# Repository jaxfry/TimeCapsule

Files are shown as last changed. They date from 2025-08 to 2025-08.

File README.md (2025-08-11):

# Time Capsule USB

## Description

**What is Time Capsule USB?**

Time Capsule USB is a custom PCB using the RP2040 microcontroller that functions as a sort of time capsule. It alows you upload files to it, which can only be accessed after a certain date that you set. Due to the limits of battery life, it's not meant to be used for long-term storage, but it should last about 7 years and then about 1 year of the LED blinking to indicate that the time has come to access the files. The main limit is that CR2032 batteries only last about 10 years and naturally discharge over time.

---

## Why I Made This

I wanted to create a simple yet fun project that would allow me to learn about PCB design and microcontrollers, using RTC and other components, I felt like I learned a lot!

---

## Features
- **RP2040 Microcontroller**: Wow! It's micro, and it controls things!
- **Storage**: A whopping 16MB of flash storage for the code and files you want to store!
- **Time Lock**: Just name the file the date you want to unlock it.
- **Battery Life**: Powered by a CR2032 battery, it can last up to 7 years. Meaning, don't go past that date, or you will lose the files!
- **RTC**: Super duper efficient clock that runs on battery for years.
- **LED indicator**: Thats right, IT EVEN HAS AN LED! Once a file is ready to be accessed, the LED will blink to indicate that the time has come. it can do this for about a year before the battery dies.

---

## How to Use
1. **Upload Files**: Connect the Time Capsule USB to your computer and upload files to it. (will appear as a USB drive)
2. **Set Unlock Date**: Name the file with the date you want to unlock it (e.g., `2025-12-31.txt`).
3. **Disconnect**: Your files will no longer appear until the date!

---

## Project Pictures
Time Capsule USB PCB

### Bill of Materials (BOM)
|Reference |Qty |Value |DNP|Exclude from BOM|Exclude from Board|Footprint |Datasheet |MANUFACTURER |MPN |DIGIKEY # |Price |Link |
|---|---|---|---|---|---|---|---|---|---|---|---|---|
|BT1 |1 |Battery_Cell | | | |Battery:BatteryHolder_Keystone_106_1x20mm |~ |Keystone Electronics |106 |36-106-ND |1.38000 |https://www.digikey.ca/en/products/detail/keystone-electronics/106/27386 |
|C1,C9,C13 |3 |1u | | | |Capacitor_SMD:C_0402_1005Metric_Pad0.74x0.62mm_HandSolder |~ |TDK Corporation |C1005X5R1E105K050EC |445-C1005X5R1E105K050ECCT-ND |0.16000 |https://www.digikey.ca/en/products/detail/tdk-corporation/C1005X5R1E105K050EC/22106056 |
|C2,C3,C4,C5,C6,C7,C8,C10,C11,C14|10 |100n | | | |Capacitor_SMD:C_0402_1005Metric_Pad0.74x0.62mm_HandSolder |~ |Samsung Electro-Mechanics |CL05B104KP5VPNC |1276-CL05B104KP5VPNCCT-ND |0.05300 |https://www.digikey.ca/en/products/detail/samsung-electro-mechanics/CL05B104KP5VPNC/20498482 |
|C12,C18 |2 |4.7uF | | | |Capacitor_SMD:C_0402_1005Metric_Pad0.74x0.62mm_HandSolder |~ |Samsung Electro-Mechanics |CL05A475MP5NRNC |1276-1482-1-ND |0.12000 |https://www.digikey.ca/en/products/detail/samsung-electro-mechanics/CL05A475MP5NRNC/3887140 |
|C15,C16 |2 |15p | | | |Capacitor_SMD:C_0402_1005Metric_Pad0.74x0.62mm_HandSolder |~ |Murata Electronics |GJM1555C1H150GB01D |490-8080-1-ND |0.17000 |https://www.digikey.ca/en/products/detail/murata-electronics/GJM1555C1H150GB01D/2592856 |
|C17 |1 |0.1u | | | |Capacitor_SMD:C_0402_1005Metric_Pad0.74x0.62mm_HandSolder |~ |Samsung Electro-Mechanics |CL05B104KP5NNNC |1276-1002-1-ND |0.12000 |https://www.digikey.ca/en/products/detail/samsung-electro-mechanics/CL05B104KP5NNNC/3886660 |
|D1 |1 |LED | | | |LED_SMD:LED_0805_2012Metric |~ |ams-OSRAM USA INC. |LS R976-NR-1-0-20-R18 |475-LSR976-NR-1CT-ND |0.23000 |https://www.digikey.ca/en/products/detail/ams-osram-usa-inc/LS-R976-NR-1-0-20-R18/1227987 |
|D2 |1 |1N4148 | | | |Diode_THT:D_DO-35_SOD27_P7.62mm_Horizontal |https://assets.nexperia.com/documents/data-sheet/1N4148_1N4448.pdf |MCC (Micro Commercial Components)|1N4148WL2-TP |1N4148WL2-TPMSCT-ND |0.19000 |https://www.digikey.ca/en/products/detail/mcc-micro-commercial-components/1N4148WL2-TP/6193188 |
|J1 |1 |USB_C_Receptacle_USB2.0_14P| | | |Connector_USB:USB_C_Receptacle_GCT_USB4105-xx-A_16P_TopMnt_Horizontal|https://www.usb.org/sites/default/files/documents/usb_type-c.zip |GCT |USB4105-GF-A |USB4105-GF-A |1.12000 |https://www.digikey.ca/en/products/detail/gct/USB4105-GF-A/11198441 |
|Q1 |1 |Q_PMOS_GSD | | | |Package_TO_SOT_SMD:SOT-23 |~ |Diodes Incorporated |DMP2305U-7 |DMP2305UDICT-ND |0.40000 |https://www.digikey.ca/en/products/detail/diodes-incorporated/DMP2305U-7/2052779 |
|Q2,Q3,Q4 |3 |Q_NMOS_GSD | | | |Package_TO_SOT_SMD:SOT-23 |~ |Diotec Semiconductor |2N7002 |4878-2N7002CT-ND |0.19000 |https://www.digikey.ca/en/products/detail/diotec-semiconductor/2N7002/13163336 |
|R1,R2 |2 |5.1k | | | |Resistor_SMD:R_0402_1005Metric_Pad0.72x0.64mm_HandSolder |~ |YAGEO |RC0402FR-075K1L |311-5.10KLRCT-ND |0.15000 |https://www.digikey.ca/en/products/detail/yageo/RC0402FR-075K1L/726624 |
|R3,R4 |2 |27.4 | | | |Resistor_SMD:R_0402_1005Metric_Pad0.72x0.64mm_HandSolder |~ |Stackpole Electronics Inc |RMCF0402FT27R4 |738-RMCF0402FT27R4CT-ND |0.15000 |https://www.digikey.ca/en/products/detail/stackpole-electronics-inc/RMCF0402FT27R4/1761590 |
|R6,R7 |2 |1k | | | |Resistor_SMD:R_0402_1005Metric_Pad0.72x0.64mm_HandSolder |~ |Stackpole Electronics Inc |RMCF0402FT1K00 |RMCF0402FT1K00CT-ND |0.15000 |https://www.digikey.ca/en/products/detail/stackpole-electronics-inc/RMCF0402FT1K00/1761754 |
|R8,R9 |2 |4.7k | | | |Resistor_SMD:R_0402_1005Metric_Pad0.72x0.64mm_HandSolder |~ |YAGEO |RC0402FR-074K7L |311-4.7KLRCT-ND |0.15000 |https://www.digikey.ca/en/products/detail/yageo/RC0402FR-074K7L/2827563 |
|R10 |1 |1M | | | |Resistor_SMD:R_0402_1005Metric_Pad0.72x0.64mm_HandSolder |~ |TE Connectivity Passive Product  |CRGCQ0402F1M0 |A129663CT-ND |0.15000 |https://www.digikey.ca/en/products/detail/te-connectivity-passive-product/CRGCQ0402F1M0/8576265 |
|R11 |1 |16.9k | | | |Resistor_SMD:R_0402_1005Metric_Pad0.72x0.64mm_HandSolder |~ |Panasonic Electronic Components  |ERJ-2RKF1692X |P16.9KLCT-ND |0.15000 |https://www.digikey.ca/en/products/detail/panasonic-electronic-components/ERJ-2RKF1692X/192161 |
|R12,R14,R16 |3 |10k | | | |Resistor_SMD:R_0402_1005Metric_Pad0.72x0.64mm_HandSolder |~ |Samsung Electro-Mechanics |RC1005F103CS |1276-3431-1-ND |0.15000 |https://www.digikey.ca/en/products/detail/samsung-electro-mechanics/RC1005F103CS/3903439 |
|R13 |1 |150 |DNP| | |Resistor_SMD:R_0402_1005Metric_Pad0.72x0.64mm_HandSolder |~ |Stackpole Electronics Inc |RMCF0402FT150R |RMCF0402FT150RCT-ND |0.15000 |https://www.digikey.ca/en/products/detail/stackpole-electronics-inc/RMCF0402FT150R/1761826 |
|R15 |1 |100k | | | |Resistor_SMD:R_0402_1005Metric_Pad0.72x0.64mm_HandSolder |~ |Vishay Dale |CRCW0402100KFKED |541-100KLCT-ND |0.15000 |https://www.digikey.ca/en/products/detail/vishay-dale/CRCW0402100KFKED/1178235 |
|SW1,SW2 |2 |SW_Push | | | |Button_Switch_THT:SW_PUSH_6mm |~ |Omron Electronics Inc-EMC Div |B3F-1020 |SW402-ND |0.43000 |https://www.digikey.ca/en/products/detail/omron-electronics-inc-emc-div/B3F-1020/44059 |
|U1 |1 |RP2040 | | | |Package_DFN_QFN:QFN-56-1EP_7x7mm_P0.4mm_EP3.2x3.2mm |https://datasheets.raspberrypi.com/rp2040/rp2040-datasheet.pdf |Raspberry Pi |SC0914(13) |2648-SC0914(13)CT-ND |1.07000 |https://www.digikey.ca/en/products/detail/raspberry-pi/SC0914-13/14306010 |
|U2 |1 |TPL5110 | | | |Package_TO_SOT_SMD:SOT-23-6 |http://www.ti.com/lit/ds/symlink/tpl5110.pdf |Texas Instruments |TPL5110QDDCRQ1 |296-47866-1-ND |1.24000 |https://www.digikey.ca/en/products/detail/texas-instruments/TPL5110QDDCRQ1/6816812 |
|U3 |1 |AP2112K-3.3 | | | |Package_TO_SOT_SMD:SOT-23-5 |https://www.diodes.com/assets/Datasheets/AP2112.pdf |Diodes Incorporated |AP2112K-3.3TRG1 |AP2112K-3.3TRG1DICT-ND |0.34000 |https://www.digikey.ca/en/products/detail/diodes-incorporated/AP2112K-3-3TRG1/4470746 |
|U4 |1 |RV-3028-C7 | | | |Package_SON:MicroCrystal_C7_SON-8_1.5x3.2mm_P0.9mm |https://www.microcrystal.com/fileadmin/Media/Products/RTC/Datasheet/RV-3028-C7.pdf|Micro Crystal AG |RV-3028-C7 32.768KHZ 1PPM-TA-QC|2195-RV-3028-C732.768KHZ1PPM-TA-QCCT-ND|3.91000 |https://www.digikey.ca/en/products/detail/micro-crystal-ag/RV-3028-C7-32-768KHZ-1PPM-TA-QC/10431070|
|U5 |1 |W25Q128JVS | | | |Package_SO:SOIC-8_5.3x5.3mm_P1.27mm |https://www.winbond.com/resource-files/w25q128jv_dtr%20revc%2003272018%20plus.pdf |Winbond Electronics |W25Q128JVSIQ TR |256-W25Q128JVSIQTRCT-ND |2.35000 |https://www.digikey.ca/en/products/detail/winbond-electronics/W25Q128JVSIQ-TR/5803944 |
|U6 |1 |74LVC1G32 | | | |Package_TO_SOT_SMD:SOT-23-5 |http://www.ti.com/lit/sg/scyt129e/scyt129e.pdf |Texas Instruments |SN74LVC1G32DBVR |296-9847-1-ND |0.17000 |https://www.digikey.ca/en/products/detail/texas-instruments/SN74LVC1G32DBVR/381323 |
|Y1 |1 |ABM8-272-T3 | | | |Crystal:Crystal_SMD_3225-4Pin_3.2x2.5mm | |ABRACON |ABM8-272-T3 |535-ABM8-272-T3CT-ND |0.83000 |https://www.digikey.ca/en/products/detail/abracon-llc/ABM8-272-T3/22472366 |
|PCB |5 (minimum)| | | | | | | | |PCB |$2.76 (exc. shipping), $35.01 (CAD) (including shipping)|JLCPCB |
| | | | | | | | | | |Total | |$21.38 (CAD) (excluding shipping, taxes) |

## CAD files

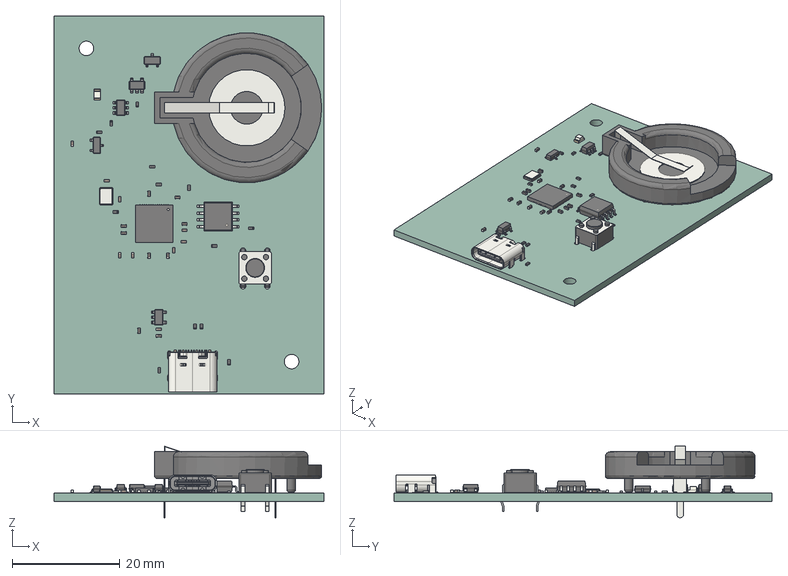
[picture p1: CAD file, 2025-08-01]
TimeCapsulePCB/TimeCapsule.step
50.0 x 70.0 x 13.2 mm
R_0402_1005Metric x 13
C_0402_1005Metric x 18
SOT-23-6
QFN-56-1EP_7x7mm_P0.4mm_EP3.2x3.2mm
SW_PUSH_6mm
SOIC-8_5.3x5.3mm_P1.27mm
SOT-23-5 x 2
SOT-23 x 2
BatteryHolder_Keystone_106_1x20mm
LED_0805_2012Metric
Crystal_SMD_3225-4Pin_3.2x2.5mm
USB_C_Receptacle_GCT_USB4105-xx-A_16P_TopMnt_Horizontal
TimeCapsule_PCB

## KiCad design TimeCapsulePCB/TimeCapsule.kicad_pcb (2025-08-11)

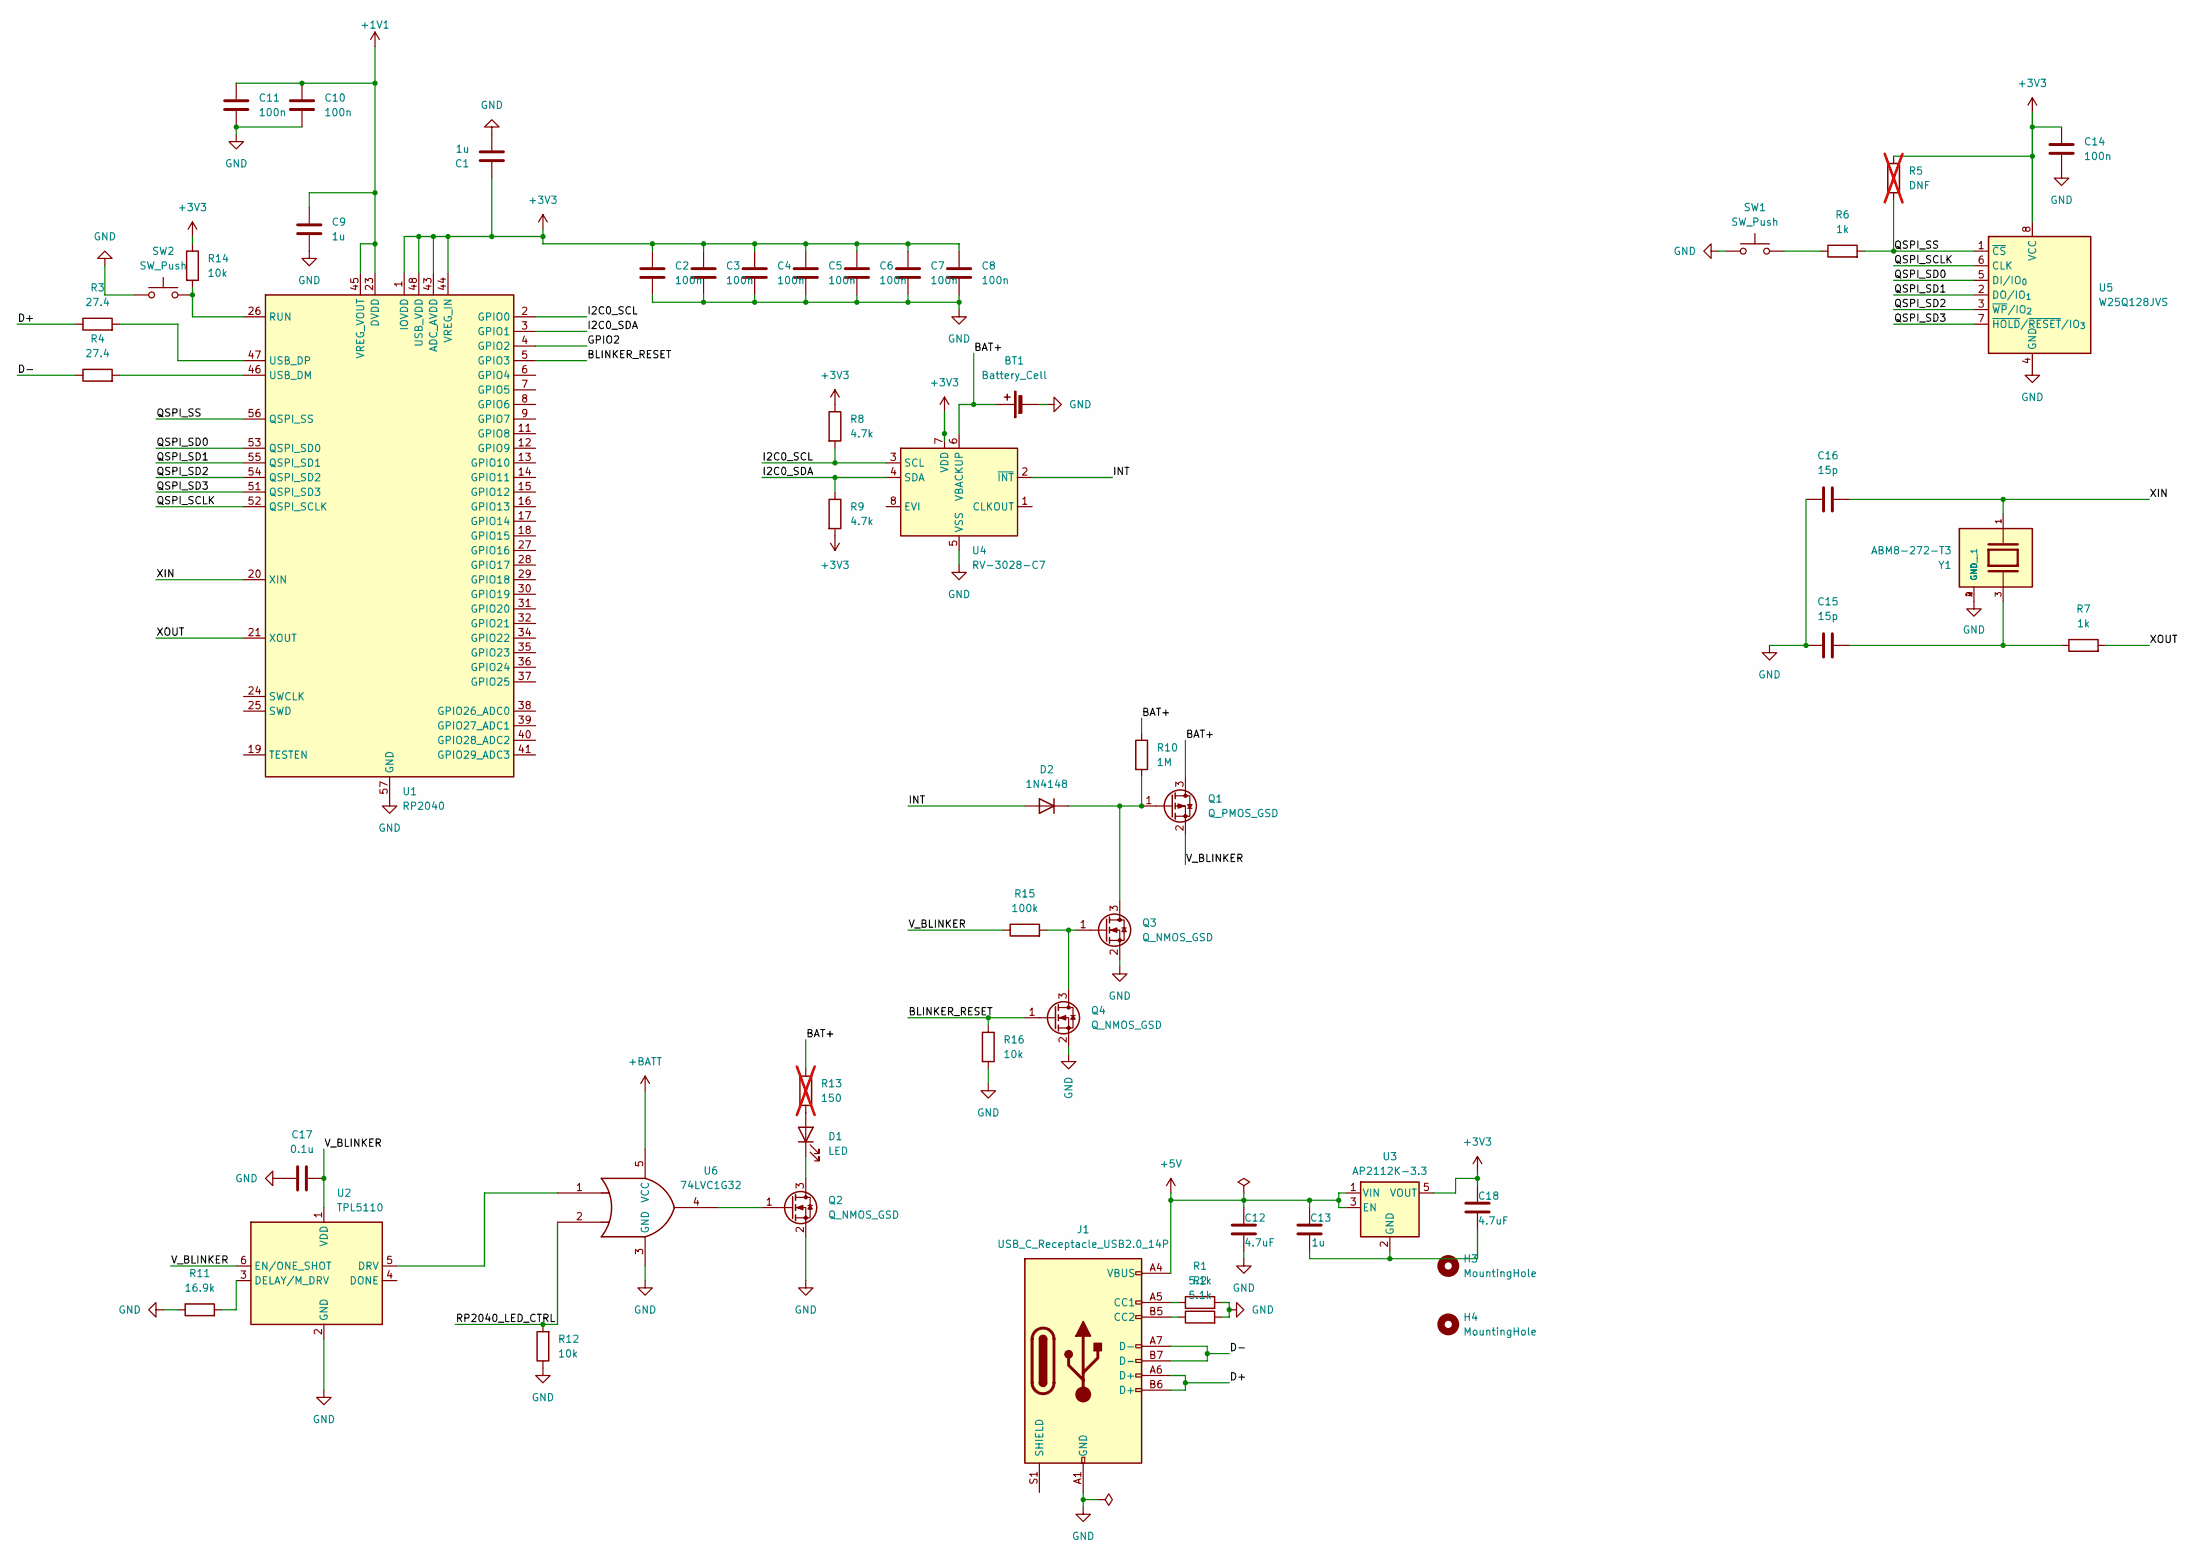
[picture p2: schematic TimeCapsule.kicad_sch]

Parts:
BT1: Battery_Cell; BatteryHolder_Keystone_106_1x20mm; MPN 106; DIGIKEY # 36-106-ND
C1, C9, C13: 1u; C_0402_1005Metric_Pad0.74x0.62mm_HandSolder; MPN C1005X5R1E105K050EC; DIGIKEY # 445-C1005X5R1E105K050ECCT-ND
C2, C3, C4, C5, C6, C7, C8, C10, C11, C14: 100n; C_0402_1005Metric_Pad0.74x0.62mm_HandSolder; MPN CL05B104KP5VPNC; DIGIKEY # 1276-CL05B104KP5VPNCCT-ND
C12, C18: 4.7uF; C_0402_1005Metric_Pad0.74x0.62mm_HandSolder; MPN CL05A475MP5NRNC; DIGIKEY # 1276-1482-1-ND
C15, C16: 15p; C_0402_1005Metric_Pad0.74x0.62mm_HandSolder; MPN GJM1555C1H150GB01D; DIGIKEY # 490-8080-1-ND
C17: 0.1u; C_0402_1005Metric_Pad0.74x0.62mm_HandSolder; MPN CL05B104KP5NNNC; DIGIKEY # 1276-1002-1-ND
D1: LED; LED_0805_2012Metric; MPN LS R976-NR-1-0-20-R18; DIGIKEY # 475-LSR976-NR-1CT-ND
D2: 1N4148; D_DO-35_SOD27_P7.62mm_Horizontal; MPN 1N4148WL2-TP; DIGIKEY # 1N4148WL2-TPMSCT-ND
H3, H4: MountingHole; MountingHole_2.7mm_M2.5
J1: USB_C_Receptacle_USB2.0_14P; USB_C_Receptacle_GCT_USB4105-xx-A_16P_TopMnt_Horizontal; MPN USB4105-GF-A; DIGIKEY # USB4105-GF-A
Q1: Q_PMOS_GSD; SOT-23; MPN DMP2305U-7; DIGIKEY # DMP2305UDICT-ND
Q2, Q3, Q4: Q_NMOS_GSD; SOT-23; MPN 2N7002; DIGIKEY # 4878-2N7002CT-ND
R1, R2: 5.1k; R_0402_1005Metric_Pad0.72x0.64mm_HandSolder; MPN RC0402FR-075K1L; DIGIKEY # 311-5.10KLRCT-ND
R3, R4: 27.4; R_0402_1005Metric_Pad0.72x0.64mm_HandSolder; MPN RMCF0402FT27R4; DIGIKEY # 738-RMCF0402FT27R4CT-ND
R5: DNF; R_0402_1005Metric_Pad0.72x0.64mm_HandSolder; not fitted
R6, R7: 1k; R_0402_1005Metric_Pad0.72x0.64mm_HandSolder; MPN RMCF0402FT1K00; DIGIKEY # RMCF0402FT1K00CT-ND
R8, R9: 4.7k; R_0402_1005Metric_Pad0.72x0.64mm_HandSolder; MPN RC0402FR-074K7L; DIGIKEY # 311-4.7KLRCT-ND
R10: 1M; R_0402_1005Metric_Pad0.72x0.64mm_HandSolder; MPN CRGCQ0402F1M0; DIGIKEY # A129663CT-ND
R11: 16.9k; R_0402_1005Metric_Pad0.72x0.64mm_HandSolder; MPN ERJ-2RKF1692X; DIGIKEY # P16.9KLCT-ND
R12, R14, R16: 10k; R_0402_1005Metric_Pad0.72x0.64mm_HandSolder; MPN RC1005F103CS; DIGIKEY # 1276-3431-1-ND
R13: 150; R_0402_1005Metric_Pad0.72x0.64mm_HandSolder; MPN RMCF0402FT150R; DIGIKEY # RMCF0402FT150RCT-ND; not fitted
R15: 100k; R_0402_1005Metric_Pad0.72x0.64mm_HandSolder; MPN CRCW0402100KFKED; DIGIKEY # 541-100KLCT-ND
SW1, SW2: SW_Push; SW_PUSH_6mm; MPN B3F-1020; DIGIKEY # SW402-ND
U1: RP2040; QFN-56-1EP_7x7mm_P0.4mm_EP3.2x3.2mm; MPN SC0914(13); DIGIKEY # 2648-SC0914(13)CT-ND
U2: TPL5110; SOT-23-6; MPN TPL5110QDDCRQ1; DIGIKEY # 296-47866-1-ND
U3: AP2112K-3.3; SOT-23-5; MPN AP2112K-3.3TRG1; DIGIKEY # AP2112K-3.3TRG1DICT-ND
U4: RV-3028-C7; MicroCrystal_C7_SON-8_1.5x3.2mm_P0.9mm; MPN RV-3028-C7 32.768KHZ 1PPM-TA-QC; DIGIKEY # 2195-RV-3028-C732.768KHZ1PPM-TA-QCCT-ND
U5: W25Q128JVS; SOIC-8_5.3x5.3mm_P1.27mm; MPN W25Q128JVSIQ TR; DIGIKEY # 256-W25Q128JVSIQTRCT-ND
U6: 74LVC1G32; SOT-23-5; MPN SN74LVC1G32DBVR; DIGIKEY # 296-9847-1-ND
Y1: ABM8-272-T3; Crystal_SMD_3225-4Pin_3.2x2.5mm; PARTREV 07-29-20; DIGIKEY # 535-ABM8-272-T3CT-ND

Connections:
+1V1: C9.1, C10.1, C11.1, U1.23 (DVDD), U1.45 (VREG_VOUT), U1.50 (DVDD)
+3V3: C1.1, C2.1, C3.1, C4.1, C5.1, C6.1, C7.1, C8.1, C14.1, C18.1, R5.1, R8.1, R9.2, R14.1, U1.1 (IOVDD), U1.10 (IOVDD), U1.22 (IOVDD), U1.33 (IOVDD), U1.42 (IOVDD), U1.43 (ADC_AVDD), U1.44 (VREG_IN), U1.48 (USB_VDD), U1.49 (IOVDD), U3.5 (VOUT), U4.7 (VDD), U5.8 (VCC)
+5V: C12.1, C13.1, J1.A4 (VBUS), J1.A9 (VBUS), J1.B4 (VBUS), J1.B9 (VBUS), U3.1 (VIN), U3.3 (EN)
+BATT: U6.5 (VCC)
/BAT+: BT1.1 (+), Q1.3 (D), R10.1, R13.1, U4.6 (VBACKUP)
/BLINKER_RESET: Q4.1 (G), R16.1, U1.5 (GPIO3)
/D+: J1.A6 (D+), J1.B6 (D+), R3.1
/D-: J1.A7 (D-), J1.B7 (D-), R4.1
/GPIO2: U1.4 (GPIO2)
/I2C0_SCL: R8.2, U1.2 (GPIO0), U4.3 (SCL)
/I2C0_SDA: R9.1, U1.3 (GPIO1), U4.4 (SDA)
/INT: D2.2 (A), U4.2 (~INT)
/QSPI_SCLK: U1.52 (QSPI_SCLK), U5.6 (CLK)
/QSPI_SD0: U1.53 (QSPI_SD0), U5.5 (DI/IO_{0})
/QSPI_SD1: U1.55 (QSPI_SD1), U5.2 (DO/IO_{1})
/QSPI_SD2: U1.54 (QSPI_SD2), U5.3 (~WP/IO_{2})
/QSPI_SD3: U1.51 (QSPI_SD3), U5.7 (~HOLD/~RESET/IO_{3})
/QSPI_SS: R5.2, R6.2, U1.56 (QSPI_SS), U5.1 (~CS)
/RP2040_LED_CTRL: R12.2, U6.2
/V_BLINKER: C17.2, Q1.2 (S), R15.1, U2.1 (VDD), U2.6 (EN/ONE_SHOT)
/XIN: C16.2, U1.20 (XIN), Y1.1
/XOUT: R7.2, U1.21 (XOUT)
GND: BT1.2 (-), C1.2, C2.2, C3.2, C4.2, C5.2, C6.2, C7.2, C8.2, C9.2, C10.2, C11.2, C12.2, C14.2, C15.1, C16.1, C17.1, J1.A1 (GND), J1.A12 (GND), J1.B1 (GND), J1.B12 (GND), Q2.2 (S), Q3.2 (S), Q4.2 (S), R1.2, R2.2, R11.1, R12.1, R16.2, SW1.1, SW2.1, U1.57 (GND), U2.2 (GND), U4.5 (VSS), U5.4 (GND), U6.3 (GND), Y1.2 (GND), Y1.4 (GND__1)
unnamed: C15.2, R7.1, Y1.3
unnamed: D1.2 (A), R13.2
unnamed: D1.1 (K), Q2.3 (D)
unnamed: D2.1 (K), Q1.1 (G), Q3.3 (D), R10.2
unnamed: J1.A5 (CC1), R1.1
unnamed: J1.B5 (CC2), R2.1
unnamed: Q2.1 (G), U6.4
unnamed: Q3.1 (G), Q4.3 (D), R15.2
unnamed: R6.1, SW1.2
unnamed: R14.2, SW2.2, U1.26 (RUN)
unnamed: R4.2, U1.46 (USB_DM)
unnamed: R3.2, U1.47 (USB_DP)
unnamed: R11.2, U2.3 (DELAY/M_DRV)
unnamed: U2.5 (DRV), U6.1
unnamed: C13.2, C18.2, U3.2 (GND)

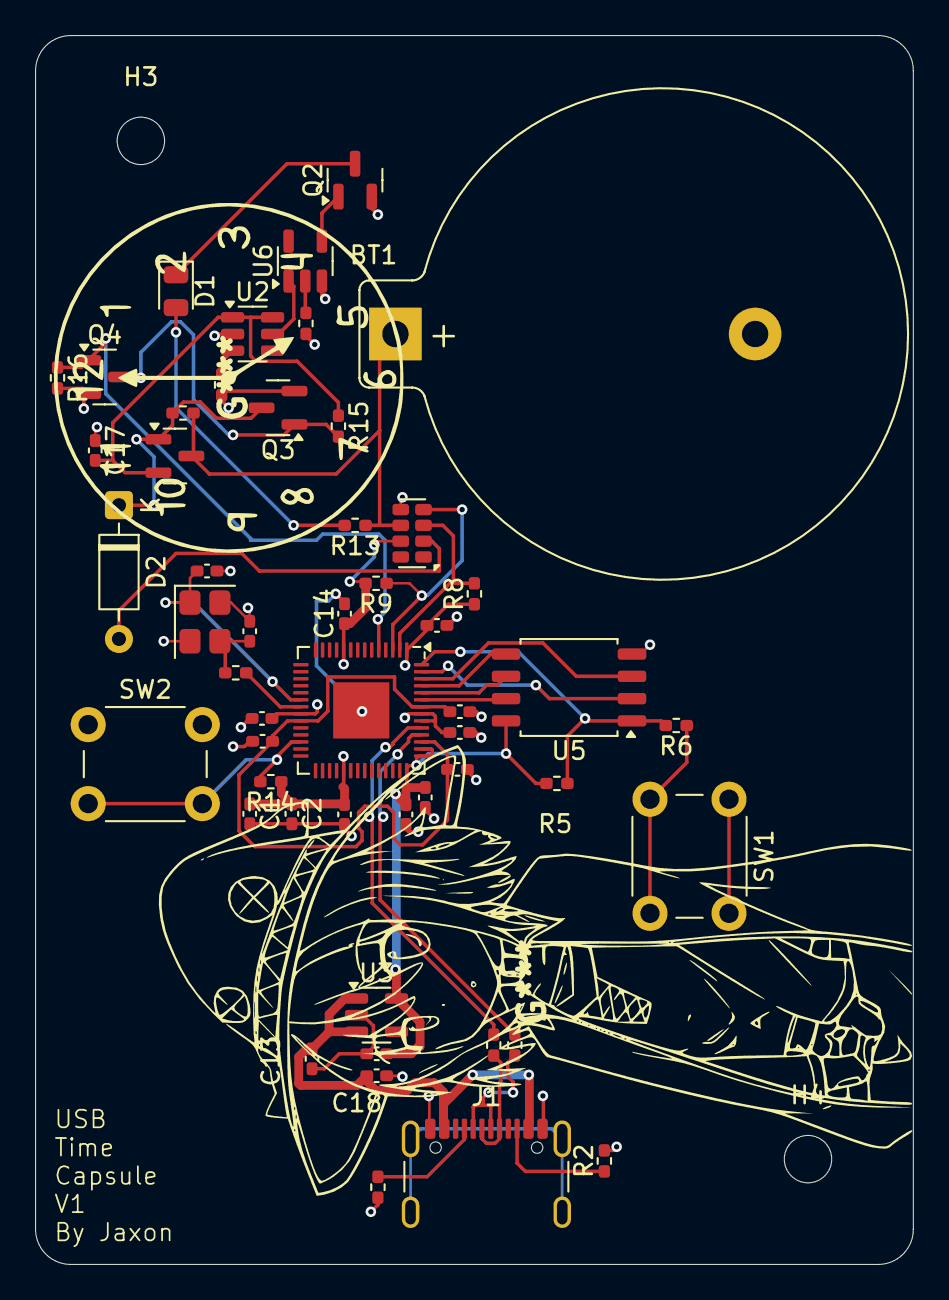
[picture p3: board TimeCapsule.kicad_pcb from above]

Board: 2 copper layers, 50.0 x 70.0 mm, 53 parts (0 on the bottom side), 36 nets.

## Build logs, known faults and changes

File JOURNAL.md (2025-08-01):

---
title: "USB Time Capsule"
author: "Jaxon"
description: "A USB drive that functions as a time capsule, storing files that can only be accessed after a certain date."
created_at: "2025-07-24"
total_time: "28.5 hours"
---
# 24 July 2025 - Research and Beginning Schematic (3.5 hours)
Sch
- As I've never A) designed a PCB before and B) have minimal experience with hardware, I decided to start with gathering resources like the official RP2040 guide and watched some video explanations of how things like Decoupling Capacitors work. It took a while to wrap my head around how it worked.
- I started slowly creating the schematic in KiCad, figuring out how everything should be connected.
Although it's only been the first day, it's crazy how much I felt like I learned already. I feel like I'm finally understanding how everything fits together.

# 25 July 2025 - Schematics work (3 hours)
- I continued working on the schematic, and I learned that you can label wires with the same name to connect them. I can't believe I didn't know that before, it's so much better.
- Either way, I made major progress on the schematic and I think I have most of it done.
# 26 July 2025 - Schematic (not) finished (2 hours)
- I finished the schematic, at least I thought I did.
- Turns out I misunderstood how the RTC clock worked, so I have to redo some of the schematic. I started researching how to get the LED to blink for a long time
# 28 July 2025 - Schematic redone (2 hours)
- I completely finished the schematic!
Sch
# 29 July 2025 - PCB design (2 hours)
- I placed all the components on the PCB and started routing the wires.
- I had to make a few changes to the schematic, but nothing major.
(I forgot to take a screenshot at this point, but look at the next one to get an idea of how it looked)
# 30 July 2025 - PCB design FINISHED (7 hours)
- I finished routing the PCB, and WOW did it take an age. I guess it's because I didn't really know what I was doing, but still :skull:
- It's really space inefficient, but I don't really care.
- YAY! I'm so close! It's my first PCB design, I just hope I didn't make any mistakes.
PCB
- I also started working on the BOM
# 31 July 2025 - Last Sprint! (9 Hours)
- I finished picking the components, and I made the BOM!
- I added some random art to the PCB from the internet.
ART
- I wrote the firmware for the device
- I made some last minute fixes to the PCB

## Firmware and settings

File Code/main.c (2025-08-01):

#include <stdio.h>
#include <string.h>

#include "pico/stdlib.h"
#include "hardware/flash.h"
#include "bsp/board.h"
#include "tusb.h"

#include <time.h>
#include "rv3028.h"
#include "fs_manager.h"

#define FLASH_TARGET_BASE_ADDR (XIP_BASE)
#define FLASH_FILESYSTEM_OFFSET (2 * 1024 * 1024)

const uint32_t FLASH_TOTAL_SIZE = 16 * 1024 * 1024;
const uint32_t DISK_SIZE = FLASH_TOTAL_SIZE - FLASH_FILESYSTEM_OFFSET;

void tud_msc_capability_cb(uint8_t lun, uint32_t* block_count, uint16_t* block_size) {
    *block_size = 512;
    *block_count = DISK_SIZE / *block_size;
}

int32_t tud_msc_read_cb(uint8_t lun, uint32_t lba, uint32_t offset, void* buffer, uint32_t bufsize) {
    const uint32_t flash_addr = FLASH_TARGET_BASE_ADDR + FLASH_FILESYSTEM_OFFSET + (lba * 512);
    flash_read(flash_addr, buffer, bufsize);
    return bufsize;
}

static uint8_t sector_buffer[FLASH_SECTOR_SIZE];
int32_t tud_msc_write10_cb(uint8_t lun, uint32_t lba, uint32_t offset, uint8_t* buffer, uint32_t bufsize) {
    uint32_t block_addr_in_flash = FLASH_FILESYSTEM_OFFSET + (lba * 512);
    uint32_t sector_addr_in_flash = block_addr_in_flash & ~(FLASH_SECTOR_SIZE - 1);
    flash_read(FLASH_TARGET_BASE_ADDR + sector_addr_in_flash, sector_buffer, FLASH_SECTOR_SIZE);
    
    uint32_t offset_in_sector = block_addr_in_flash - sector_addr_in_flash;
    memcpy(sector_buffer + offset_in_sector, buffer, bufsize);

    uint32_t ints = save_and_disable_interrupts();
    flash_range_erase(sector_addr_in_flash, FLASH_SECTOR_SIZE);
    flash_range_program(sector_addr_in_flash, sector_buffer, FLASH_SECTOR_SIZE);
    restore_interrupts(ints);

    return bufsize;
}

void setup_rtc(void) {
    i2c_init(RV3028_I2C_PORT, 100 * 1000);
    gpio_set_function(4, GPIO_FUNC_I2C); // Corrected I2C pins
    gpio_set_function(5, GPIO_FUNC_I2C);
    gpio_pull_up(4);
    gpio_pull_up(5);
    sleep_ms(100);

    if (rv3028_initialize() != RV3028_SUCCESS) {
        printf("Error: RTC not found!\n");
        return;
    }

    struct tm current_time;
    rv3028_get_current_time(&current_time);

    if (current_time.tm_year < 123) { // Check if RTC year < 2023
        printf("Setting RTC to compile time...\n");
        char s_month[5];
        int month, day, year, hour, min, sec;
        static const char month_names[] = "JanFebMarAprMayJunJulAugSepOctNovDec";
        sscanf(__DATE__, "%s %d %d", s_month, &day, &year);
        sscanf(__TIME__, "%d:%d:%d", &hour, &min, &sec);
        month = (strstr(month_names, s_month) - month_names) / 3;

        struct tm compile_time = { .tm_sec = sec, .tm_min = min, .tm_hour = hour, .tm_mday = day, .tm_mon = month, .tm_year = year - 1900 };
        rv3028_set_current_time(&compile_time);
    }
}

void check_and_process_files(void) {
    bool is_alarm_triggered;
    rv3028_check_alarm_flag(&is_alarm_triggered);

    if (is_alarm_triggered) {
        printf("Alarm triggered! Checking for unlock.\n");
        
        // Clear the alarm flag first to avoid re-triggering
        rv3028_clear_alarm_flag();

        if (fs_is_file_in_private()) {
            struct tm unlock_date, current_time;
            fs_get_unlock_date(&unlock_date);
            rv3028_get_current_time(&current_time);

            if (mktime(&current_time) >= mktime(&unlock_date)) {
                printf("Unlock date reached! Moving file to public.\n");
                fs_move_to_public();

                // After unlocking, check for the next locked file and set a new alarm
                if (fs_is_file_in_private()) {
                    struct tm next_unlock_date;
                    fs_get_unlock_date(&next_unlock_date);
                    rv3028_set_alarm(&next_unlock_date);
                    printf("Next alarm set for new file.\n");
                } else {
                    printf("No more locked files. Disabling alarm.\n");
                    rv3028_disable_alarm_interrupt();
                }
            }
        }
    }

    // This part handles the initial locking of a new file
    if (!fs_is_file_in_private()) {
        char filename[256];
        if (fs_find_file_in_public(filename, sizeof(filename))) {
            if (fs_is_file_stable(filename)) {
                printf("New file found: %s. Moving to private.\n", filename);
                fs_move_to_private(filename);

                // Set alarm for the new file's unlock date
                struct tm unlock_date;
                fs_get_unlock_date(&unlock_date);
                rv3028_set_alarm(&unlock_date);
                printf("Alarm set for the new locked file.\n");
            }
        }
    }
}

void check_and_disable_latch(void) {
    struct tm current_time, unlock_date;
    
    rv3028_get_current_time(&current_time);

    if (fs_is_file_in_private() && fs_get_unlock_date(&unlock_date)) {
        if (mktime(&current_time) >= mktime(&unlock_date)) {
            printf("Unlock date has passed. Disabling MOSFET latch.\n");

            // Temporarily take control of GPIO5
            gpio_set_function(5, GPIO_FUNC_SIO);
            gpio_set_dir(5, GPIO_OUT);
            
            gpio_put(5, 1); // Drive GPIO5 high
            sleep_ms(500);  // Keep it high for a moment
            gpio_put(5, 0); // Drive GPIO5 low again

            // Return GPIO5 to I2C function
            gpio_set_function(5, GPIO_FUNC_I2C);
            gpio_pull_up(5);
        }
    }
}

int main(void) {
    board_init();
    stdio_init_all();
    printf("Pico Time Capsule Initializing...\n");

    setup_rtc();
    fs_init();
    fs_mount_partitions();

    check_and_disable_latch();

    tusb_init();

    while (1) {
        tud_task();
        check_and_process_files();
    }

    return 0;
}

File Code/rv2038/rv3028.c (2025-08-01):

#include "rv3028.h"
#include <time.h>

// Constants for validation
#define MAX_SECONDS     59
#define MAX_MINUTES     59
#define MAX_HOURS       23
#define MAX_DAY_OF_MONTH 31
#define MAX_MONTH       11  // tm_mon is 0-11
#define MAX_WEEKDAY     6
#define MAX_BCD_VALUE   99
#define BCD_ERROR_VALUE 0xFF
#define YEAR_OFFSET_1900 100  // Years since 1900 for 2000+ dates

// BCD Conversion Functions
uint8_t decimal_to_bcd(uint8_t decimal_value) {
    if (decimal_value > MAX_BCD_VALUE) {
        return BCD_ERROR_VALUE;
    }
    return ((decimal_value / 10) << 4) | (decimal_value % 10);
}

uint8_t bcd_to_decimal(uint8_t bcd_value) {
    return ((bcd_value >> 4) * 10) + (bcd_value & 0x0F);
}

// I2C Communication Helpers
static rv3028_result_t write_register_address(uint8_t register_address) {
    int result = i2c_write_blocking(RV3028_I2C_PORT, RV3028_I2C_ADDR, 
                                   &register_address, 1, true);
    return (result == 1) ? RV3028_SUCCESS : RV3028_ERROR_I2C_WRITE_FAILED;
}

static rv3028_result_t read_registers(uint8_t *buffer, size_t buffer_size) {
    int result = i2c_read_blocking(RV3028_I2C_PORT, RV3028_I2C_ADDR, 
                                  buffer, buffer_size, false);
    return (result == (int)buffer_size) ? RV3028_SUCCESS : RV3028_ERROR_I2C_READ_FAILED;
}

static rv3028_result_t write_data_to_device(const uint8_t *data, size_t data_size) {
    int result = i2c_write_blocking(RV3028_I2C_PORT, RV3028_I2C_ADDR, 
                                   data, data_size, false);
    return (result == (int)data_size) ? RV3028_SUCCESS : RV3028_ERROR_I2C_WRITE_FAILED;
}

// Input Validation Functions
static bool is_valid_time_component(const struct tm *time_data) {
    return (time_data->tm_sec <= MAX_SECONDS &&
            time_data->tm_min <= MAX_MINUTES && 
            time_data->tm_hour <= MAX_HOURS &&
            time_data->tm_mday <= MAX_DAY_OF_MONTH &&
            time_data->tm_mon <= MAX_MONTH &&
            time_data->tm_wday <= MAX_WEEKDAY);
}

static rv3028_result_t validate_time_input(const struct tm *time_to_validate) {
    if (time_to_validate == NULL) {
        return RV3028_ERROR_NULL_POINTER;
    }
    
    if (!is_valid_time_component(time_to_validate)) {
        return RV3028_ERROR_INVALID_TIME;
    }
    
    return RV3028_SUCCESS;
}

// Device Communication Functions
rv3028_result_t rv3028_initialize(void) {
    rv3028_result_t result = write_register_address(RV3028_STATUS_REG);
    if (result != RV3028_SUCCESS) {
        return result;
    }
    
    uint8_t status_data;
    result = read_registers(&status_data, 1);
    if (result != RV3028_SUCCESS) {
        return RV3028_ERROR_DEVICE_NOT_RESPONDING;
    }

    return RV3028_SUCCESS;
}

// Time Setting Functions
static void populate_time_write_buffer(uint8_t *buffer, const struct tm *time_data) {
    buffer[0] = RV3028_SECONDS_REG;  // Starting register address
    buffer[1] = decimal_to_bcd(time_data->tm_sec);
    buffer[2] = decimal_to_bcd(time_data->tm_min);
    buffer[3] = decimal_to_bcd(time_data->tm_hour);
    buffer[4] = decimal_to_bcd(time_data->tm_wday);
    buffer[5] = decimal_to_bcd(time_data->tm_mday);
    buffer[6] = decimal_to_bcd(time_data->tm_mon + 1);    // RTC expects 1-12, tm_mon is 0-11
    buffer[7] = decimal_to_bcd(time_data->tm_year % 100); // RTC stores 2-digit year
}

rv3028_result_t rv3028_set_current_time(const struct tm *time_to_set) {
    rv3028_result_t validation_result = validate_time_input(time_to_set);
    if (validation_result != RV3028_SUCCESS) {
        return validation_result;
    }

    uint8_t write_buffer[RV3028_WRITE_BUFFER_SIZE];
    populate_time_write_buffer(write_buffer, time_to_set);
    
    return write_data_to_device(write_buffer, sizeof(write_buffer));
}

// Time Reading Functions
static void convert_rtc_registers_to_tm(const uint8_t *rtc_registers, struct tm *time_buffer) {
    time_buffer->tm_sec  = bcd_to_decimal(rtc_registers[0] & RV3028_SECONDS_MASK);
    time_buffer->tm_min  = bcd_to_decimal(rtc_registers[1] & RV3028_MINUTES_MASK);
    time_buffer->tm_hour = bcd_to_decimal(rtc_registers[2] & RV3028_HOURS_MASK);
    time_buffer->tm_wday = bcd_to_decimal(rtc_registers[3] & RV3028_WEEKDAY_MASK);
    time_buffer->tm_mday = bcd_to_decimal(rtc_registers[4] & RV3028_DATE_MASK);
    time_buffer->tm_mon  = bcd_to_decimal(rtc_registers[5] & RV3028_MONTH_MASK) - 1; // Convert 1-12 to 0-11
    time_buffer->tm_year = bcd_to_decimal(rtc_registers[6]) + YEAR_OFFSET_1900;      // Convert to years since 1900

    // Set fields that the RTC doesn't provide
    time_buffer->tm_isdst = -1; // Unknown DST status
    time_buffer->tm_yday = 0;   // Day of year not calculated
}

rv3028_result_t rv3028_get_current_time(struct tm *time_buffer) {
    if (time_buffer == NULL) {
        return RV3028_ERROR_NULL_POINTER;
    }
    
    rv3028_result_t result = write_register_address(RV3028_SECONDS_REG);
    if (result != RV3028_SUCCESS) {
        return result;
    }

    uint8_t rtc_registers[RV3028_TIME_REGISTER_COUNT];
    result = read_registers(rtc_registers, sizeof(rtc_registers));
    if (result != RV3028_SUCCESS) {
        return result;
    }

    convert_rtc_registers_to_tm(rtc_registers, time_buffer);
    return RV3028_SUCCESS;
}

// Alarm Functions
rv3028_result_t rv3028_set_alarm(const struct tm *unlock_date) {
    rv3028_result_t validation_result = validate_time_input(unlock_date);
    if (validation_result != RV3028_SUCCESS) {
        return validation_result;
    }

    // Disable alarm interrupt to prevent race conditions
    uint8_t control_buffer[] = {RV3028_CONTROL2_REG, 0};
    rv3028_result_t result = write_data_to_device(control_buffer, sizeof(control_buffer));
    if (result != RV3028_SUCCESS) {
        return result;
    }

    // Set alarm registers
    // Set alarm registers, enabling minute, hour, and day of month alarms.
    // The AE_x bit is active-low, so we clear it to enable the alarm.
    uint8_t alarm_buffer[] = {
        RV3028_ALARM_MINUTES_REG,
        decimal_to_bcd(unlock_date->tm_min) & ~RV3028_ALARM_AE,
        decimal_to_bcd(unlock_date->tm_hour) & ~RV3028_ALARM_AE,
        decimal_to_bcd(unlock_date->tm_mday) & ~RV3028_ALARM_AE
    };
    result = write_data_to_device(alarm_buffer, sizeof(alarm_buffer));
    if (result != RV3028_SUCCESS) {
        return result;
    }

    // Enable alarm interrupt
    control_buffer[1] = RV3028_STATUS_AIE;
    return write_data_to_device(control_buffer, sizeof(control_buffer));
}
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

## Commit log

2025-08-01 EVERYTHING LAST MINUTE
    [BOM.csv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]
2025-08-01 price BOM
    [BOM.csv]
2025-08-01 Update Price
    [BOM.csv]
2025-08-11 Update readme and BOM
    [BOM.csv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]
